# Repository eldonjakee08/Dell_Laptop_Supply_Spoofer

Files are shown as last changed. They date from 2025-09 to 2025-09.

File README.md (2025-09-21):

# Dell Laptop Supply Spoofer
So I have this old Dell Inspiron 3593 (2020 model) laptop and it's showing its age, with the battery being slightly bloated and high wear level of 40%. 😅



I know! I know! I should replace the battery 😅, but I kind of thought "hey why not power the laptop with an external powerbank?" in that way I'm not limited to the laptops internal battery. I could use my laptop anywhere for many hours without having to worry about a power source. 

I'm an outdoor person and sometimes I get claustrophobic inside coding all day, I would like to sometimes code outdoors, like by the beach, by the park or even in cafes. But with the current state of my laptops battery, I am not able to do those things and that's the main motivation behind this little project. 

# Defining the problem
So due to my laptops relatively old age (5 years is considered old in tech years 😂), it comes installed with a 4.5mm DC power jack. So challenge #1 is, how do I convert the Type-C port that comes with modern power banks into a 4.5mm DC power jack? My answer to that is with these little guys, USB PD trigger boards.  



These boards are designed to trigger a USB Power Delivery (USB PD) capable power bank to output a specific voltage level (i.e 5V, 9V, 12V, 15V & 20V) we can then solder on its output pins a 4.5mm DC Jack cable which we can plug into the laptop. As for the power source, we will be using a 65Watt USB PD capable power bank that can output 20V and source up to 3.25A. 

So by using a 65W USB PD capable power bank + USB PD Trigger module + 4.5mm DC Power jack cable and plugging it into the laptop would make this work right???

Illustration1

Well, not quite, because Dell laptop power supplies implement an ID chip on its output stage for authenticity checking, output voltage check & output power check. 

If you just plug in a random 20V supply into the laptop it would know that it's not an authentic dell laptop supply and it would severely limit the amount of current that it would draw from it (800mA in my experience) which results in an underpowered & underclocked laptop leading to poor performance. This is our challenge #2, how to bypass the dell proprietary handshake between supply and laptop. 



Notice from the schematic, Dell uses a DS2501 EEPROM IC for its ID chip, which is a 512bit 1-Wire protocol EEPROM chip. This is where the serial number and power supply details are stored, which is then read by the laptop when the power supply is first plugged in. So in theory, if we read the data inside the DS2501 EEPROM, program it into our own ID chip and wire the data pin into the ID pin of our 4.5mm DC power jack, we should be able to bypass the authenticity check. 

So now, the whole system should look like this: 

Illustration2

# Probing the ID Chip
So I probed the ID pin of the supply with a logic analyzer to see the data being exchanged during handshake. Heres what I got. 



<br>

RESET CONDITION: The laptop issues a ~500us pulse to check if a 1-Wire slave (DS2501) is present.

PRESENCE PULSE: The DS2501 responds with a presence pulse to let the laptop know its "presence"      
<br>

SKIP ROM COMMAND: This is a 1-Wire protocol command that basically tells the DS2501 IC to skip the slave identification process.

READ MEMORY COMMAND: This command (0xF0) is used to read data inside the DS2501 EEPROM data field. 

<br>

The bus master (the laptop) follows the read memory command byte with a 2-byte address TA1:(T7:T0) = 0x06 (lower nibble address), TA2:(T15:T8) = 0x00 (higher nibble address) that indicates a starting address location within the EEPROM data field.

<br>**DATA SECTION**


DATA 0x27: This is an 8-bit CRC of the command byte and address bytes which is computed by the DS2501.

DATA 0x41,'A': Data inside memory address 0x0006 which is the start address of the READ ROM command. DS2501 auto increments the address if the master issues more read time slots. 

DATA 0x43,'C': Data inside memory address 0x0007.

DATA 0x30,'0': Data inside memory address 0x0008.

DATA 0x36,'6': Data inside memory address 0x0009.

DATA 0x35,'5': Data inside memory address 0x000A.

So if you notice, the data reads "AC065" this basically tells the laptop that its an "AC" supply thats capable of outputting 65Watts! So if we just program these values on the same memory location in our own ID chip then we could essentially bypass the handshake. 

I tried reading the whole EEPROM of the ID chip and this is what i got. 

DELL00AC065195033CN0MGJN9LOC0001V8314A08

DELL: Power supply manufacturer

AC: AC supply

65: 65 Watts capable

195: 19.5 Output Voltage

33CN0MGJN9LOC0001V8314A08: Laptop Supply Serial Number

Now we have the values to program into our ID chip! 

# Programming the ID Chip

The dell laptop supplies use a DS2501 ID Chip, I have a few problems on using this chip:

1. Its a one time programmable chip.
2. You need a 12V pulse applied to the data pins to program the EEPROM. Which we would need a separate circuit for precise 12V pulse generation.
3. Lastly, IT'S OBSOLETE! 😭

So instead, I opted for a newer chip in the same family, the DS2431 1024bit 1-Wire EEPROM IC. I think this is an improvement over the now obsolete DS2501 for the following reasons:

1. You could program the EEPROM multiple times.
2. You do not need a 12V pulse to program the chip.
3. Same EEPROM addresses and memory structure as DS2501.
4. Same ROM commands as DS2501
5. Larger memory.
6. Lastly, ITS NOT OBSOLETE! 👌

I've developed a driver for programming and reading into the EEPROM of these chips. You can download and refer to the Repo link given below on how to use the driver.

Repo Link: https://github.com/eldonjakee08/DS2431_1WIRE_EEPROM_DRIVER



I made a simple STM32 program to write into the EEPROM. Let me explain how it works. 
1. declare and intialize uint8_t pdata[] array, this will hold the first 8 bytes of data to be written into EEPROM memory location 0x0000 to 0x0007
2. call OneWire_WriteMemory() function (from the driver) to write the contents of pdata array into DS2431s EEPROM
3. declare and intialize another uint8_t pdata2[] array, this will hold the 2nd batch of 8 byte data to be written into memory location 0x0008 to 0x000F
4. call OneWire_WriteMemory() function again to write the contents of pdata2 array into DS2431s EEPROM

If you notice, in pdata[] array, theres this "0x27" byte. This data is actually the 8bit CRC generated by the DS2501 after master issues the SKIP ROM, READ MEMORY & MEMORY LOCATION commands. 

The problem with DS2431 is that, it does not generate an 8Bit CRC after master issues the previously mentioned commands. The laptop expects to get the 0x27 CRC from slave, so to solve this, we hard coded the 0x27 8bit CRC into the memory location 0x0006 of DS2431 EEPROM. 

This particular memory location is important as this is where the laptop starts to read from the ID chips EEPROM. So by the time the laptop expects an 8Bit CRC from the slave, what the DS2431 essentially does is sending the hard coded 0x27 CRC data inside the memory location 0x0006, thereby replicating the DS2501 behavior. 👌

After programming the chip we should get a message in the Serial Wire Viewer. (Shown below)



Now that we have programmed the chip, we can now proceed in assembling the hardware. 

# Assembling the Hardware

The hardware for this project is pretty simple. See schematic below. 



The output of the PD trigger is directly connected to the power lines of the 4.5mm DC jack cable. The data line of the DS2431 is directly connected to the ID line of the cable. 

If you notice, the DS2431 does not have any power rails, this is because the IC can operate in "parasitic power mode" this essentially means that it draws its power from the data lines during the read/write process. 

<br>**END PRODUCT**





<br>**TESTING**

Heres a youtube video of me testing the Supply Spoofer. 

Youtube (https://www.youtube.com/watch?v=CXdM-Me_jxc)

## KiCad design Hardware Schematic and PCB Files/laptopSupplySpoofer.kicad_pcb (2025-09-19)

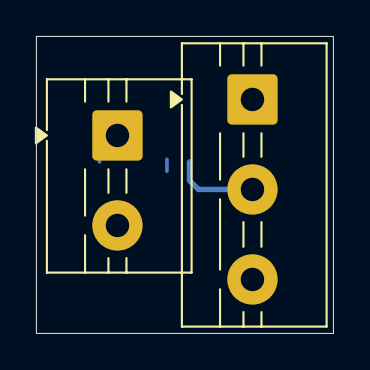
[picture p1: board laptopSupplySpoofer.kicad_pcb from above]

Board: 2 copper layers, 16.5 x 16.5 mm, 3 parts (1 on the bottom side), 3 nets.

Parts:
J1: Screw_Terminal_01x02; TerminalBlock_MaiXu_MX126-5.0-02P_1x02_P5.00mm
J2: Screw_Terminal_01x03; TerminalBlock_MaiXu_MX126-5.0-03P_1x03_P5.00mm
U1: DS2431P; TSOC-6_3.76x3.94mm_P1.27mm

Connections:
1WIRE: J2.2, U1.2 (IO)
+20V: J1.2, J2.3
GND: J1.1, J2.1, U1.1 (GND)

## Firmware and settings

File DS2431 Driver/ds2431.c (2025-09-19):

#include "ds2431.h"

static void displaydata(uint16_t startaddress, size_t bytesToRead, uint8_t *pdataBuffer);
static void GPIOMode_Input(void);
static void GPIOMode_Output(void);
static void TIM6_init(void);
static void tim_MSP_init(void);

/*blocking delay in microseconds*/
static void delay_us(uint32_t delay);

/*
 * RxBuffer for scratchpad data
 * readScratchPad[0] - TA1
 * readScratchPad[1] - TA2
 * readScratchPad[2] - E/S BYTE
 * readScratchPad[10:3] - Scratch pad Data bytes
 */
static uint8_t readScratchPad[11];

TIM_HandleTypeDef htim6 = {0};

/*Call this function before initiating onewire communication */
void OneWire_init(void)
{
	/*
	 * Intialize GPIO pins for 1-wire communication
	 * Sets GPIOA_PIN9 as output open-drain mode.
	 * You can modify the GPIO number and port at ds2431.h
	 */
	GPIOMode_Output();

	/*Set GPIO9 idle at high*/
	HAL_GPIO_WritePin(ONE_WIRE_GPIO_PORT, ONE_WIRE_PIN, GPIO_PIN_SET);

	/*Initialize TIM6 used for timebase generation for microsecond delay*/
	TIM6_init();
}

/*
 * @brief: Generates a reset pulse on the 1-Wire bus.
 */
void OneWire_Reset(void) {
	// Generate 1-Wire reset pulse

	//config GPIO to output for master to initiate reset pulse
	GPIOMode_Output();
	HAL_GPIO_WritePin(ONE_WIRE_GPIO_PORT, ONE_WIRE_PIN, GPIO_PIN_RESET);
	delay_us(490);  // Reset pulse duration
	HAL_GPIO_WritePin(ONE_WIRE_GPIO_PORT, ONE_WIRE_PIN, GPIO_PIN_SET);

	//configure GPIO as input so slave could take over the line
	GPIOMode_Input();
	delay_us(400);   // Presence pulse wait
}


/*
 * @brief: Writes one byte of data to the 1-Wire bus.
 * @param: uint8_t byte, the byte to write to the bus.
 */
void OneWire_WriteByte(uint8_t byte)
{

	/*configure GPIO as output so it could drive the 1-Wire bus*/
	GPIOMode_Output();

	// Send 8 bits (LSB first)
	for (int i = 0; i < 8; i++) {

		//initiate write time slot by pulling line to gnd for 6us. 1us <= tlow1 <= 15us DS limits
		HAL_GPIO_WritePin(ONE_WIRE_GPIO_PORT, ONE_WIRE_PIN, GPIO_PIN_RESET);
		delay_us(6);

		//send data bit then wait 55us for slave to sample data.
		HAL_GPIO_WritePin(ONE_WIRE_GPIO_PORT, ONE_WIRE_PIN, (byte & (1 << i)) ? GPIO_PIN_SET : GPIO_PIN_RESET);
		delay_us(55);  // Timing for bit transmission

		//pull the line back to IDLE state (high) and hold for 5us to prepare for next write time slot
		//60us <= tslot <= 120us DS limits.
		HAL_GPIO_WritePin(ONE_WIRE_GPIO_PORT, ONE_WIRE_PIN, GPIO_PIN_SET);
		delay_us(5);
	}
}


/*
 * @brief: Reads one byte of data from the 1-Wire bus.
 * @return: uint8_t, the byte read from the bus.
 */
uint8_t OneWire_ReadByte(void) {
	uint8_t data = 0;

	// Read 8 bits (LSB first)
	for (int i = 0; i < 8; i++) {

		GPIOMode_Output();
		HAL_GPIO_WritePin(ONE_WIRE_GPIO_PORT, ONE_WIRE_PIN, GPIO_PIN_RESET);
		delay_us(5); // Initiate read time slot
		HAL_GPIO_WritePin(ONE_WIRE_GPIO_PORT, ONE_WIRE_PIN, GPIO_PIN_SET);

		/*Set GPIO as input to let slave take over the bus*/
		GPIOMode_Input();
		delay_us(10); // Data acquisition timing

		/*If read bit is equal to 1, set the corresponding bitfield in data variable*/
		if (HAL_GPIO_ReadPin(ONE_WIRE_GPIO_PORT, ONE_WIRE_PIN) == 1) {
			data |= (1 << i);
		}

		delay_us(50); // Ensure proper slot timing
	}

	return data;
}

/*
 * @brief: Writes data into DS2431 EEPROM memory.
 ***********EEPROM WRITING GUIDELINES**************
 * 1. Write in 8-byte chunks: You can only write full 8-byte rows at a time.
 * 2. Use 8-byte aligned addresses: Writes must start at addresses divisible by 8 (e.g., 0x00, 0x08, 0x10…).
 *
 * @param: uint16_t startaddress, start address of EEPROM write.
 * @param: uint8_t *pdata, pointer to data source buffer.
 */
void OneWire_WriteMemory(uint16_t startaddress, uint8_t *pdata)
{
	printf("\n Writing into 0x%X to 0x%X\n", startaddress, (startaddress+7) );

	uint16_t CRC16;

	//send reset pulse
	OneWire_Reset();

	//write skip ROM command
	OneWire_WriteByte(0xCC);

	//write scratch pad command
	OneWire_WriteByte(0x0F);

	//master TX TA1
	OneWire_WriteByte( (uint8_t) (startaddress & 0xFF) ); // TA1

	//master TX TA2
	OneWire_WriteByte( (uint8_t) ((startaddress >> 8) & 0xFF) ); // TA2

	//write 8 bytes of data into scratch pad
	for(uint8_t i = 0 ; i < 8 ; i++)
		OneWire_WriteByte(pdata[i]); // Data Byte

	//receive generated 16bit CRC by DS2431
	CRC16 = OneWire_ReadByte();
	CRC16 |= (OneWire_ReadByte() << 8);


	printf(" !!!Scratchpad written!!!\n Display Scratchpad Data\n");

	//Read scratchpad data to verify if it matches with user data
	Read_ScratchPad(pdata);

	//Copy scratchpad data to main EEPROM
	Copy_ScratchPad();

}

/*
 * @brief: Reads and displays data from DS2431 EEPROM memory.
 * @param: uint16_t startaddress, start address of EEPROM read.
 * @param: size_t bytesToRead, number of bytes to read from start address.
 * @param: uint8_t *pdataBuffer, pointer to data buffer where read data will be stored.
 */
void OneWire_ReadMemory(uint16_t startaddress, size_t bytesToRead, uint8_t *pdataBuffer)
{

	OneWire_Reset();

	//skip ROM command
	OneWire_WriteByte(0xCC);

	//Read memory command
	OneWire_WriteByte(0xF0);

	OneWire_WriteByte( (uint8_t) (startaddress & 0xFF) ); // TA1

	OneWire_WriteByte( (uint8_t) ((startaddress >> 8) & 0xFF) ); // TA2

	for(uint32_t i=0 ; i < bytesToRead ; i++)
	{
		//Save read byte to rxbuffer
		pdataBuffer[i] = OneWire_ReadByte();

	}
	OneWire_Reset();

	displaydata(startaddress, bytesToRead, pdataBuffer);
}


static void displaydata(uint16_t startaddress, size_t bytesToRead, uint8_t *pdataBuffer)
{

	printf("\n Read Data from Address: 0x%X to 0x%X\n", startaddress, ( (startaddress + bytesToRead) -1) );

	for(uint32_t i=0 ; i < bytesToRead ; i++)
	{
		printf(" 0x%X\n", pdataBuffer[i]);
	}
}

/*Sets 1-Wire GPIO as input mode*/
static void GPIOMode_Input(void)
{
	// Reconfigure the pin as input to allow slave to pull the bus low
	GPIO_InitTypeDef GPIO_InitStruct = {0};

	GPIO_InitStruct.Pin = ONE_WIRE_PIN;
	GPIO_InitStruct.Mode = GPIO_MODE_INPUT;  // Set pin to input mode
	GPIO_InitStruct.Pull = GPIO_NOPULL;     // No pull-up or pull-down
	HAL_GPIO_Init(ONE_WIRE_GPIO_PORT, &GPIO_InitStruct);
}

/*Sets 1-Wire GPIO as output mode*/
static void GPIOMode_Output(void)
{
	// Reconfigure the pin as input to allow slave to pull the bus low
	GPIO_InitTypeDef GPIO_InitStruct = {0};

	GPIO_InitStruct.Pin = ONE_WIRE_PIN;
	GPIO_InitStruct.Mode = GPIO_MODE_OUTPUT_OD;  // Set pin to input mode
	GPIO_InitStruct.Pull = GPIO_NOPULL;     // No pull-up or pull-down
	HAL_GPIO_Init(ONE_WIRE_GPIO_PORT, &GPIO_InitStruct);
}
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
